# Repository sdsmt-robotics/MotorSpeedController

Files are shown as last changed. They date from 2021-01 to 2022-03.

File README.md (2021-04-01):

# MotorSpeedController  
yaya.

# Hardware  

# Software  
Contains code for the controller itself and code for a master device to interface with the controller.  
 * **controller** - Code for the speed controller itself.  
 * **controllerInterfaceLib** - Library files for use on a master device to interface with the controller.  
 
  ## Wiring Connections and Interface  
 This controller uses standard SPI communications.  
| Arduino | Speed Controller |
|---|---|
| 5V | 5V |
| GND | GND |
| MOSI | MOSI |
| MISO | MISO |
| SCK | SCK |
| SS* | SS |  

*The SS pin must be used for *at least one* of the connections. Additional speed controllers may use other digital IO pins.  
  
## Status LED  
The green LED on the board will indicate state of the controller. The key is as follows.
| State | Pattern |
|---|---|
| Off | ---------  |
| Brake | -\_\_-\_\_-\_\_  |
| Speed Control | --\_\_--\_\_-- |
| Power Control | --\_--\_--\_  |
| Timeout | -\_-\_-\_-\_-  |  
 
## Interface Lib Usage  
**Create:**  
Create an instance of the class.  

    Nidec24hController motor(SPI, ssPin);  

*SPI* - the SPI singleton object from the SPI.h library.  
*ssPin* - pin to use as chip select. Should simply be SS for first controller.  

**Initialize:**  
Create an instance of the class.  

    setup() {
        ...
        // Init SPI
        SPI.begin ();
        SPI.setClockDivider(SPI_CLOCK_DIV4);
        
        //Init motor controller
        motor.init();  
        ...
    }

**Set Speed:**  
Set the speed for the motor in RPM. Negative values are allowed. This will switch the motor to speed control mode if in power control mode or braking.  

    motor.setSpeed(speed);  

*speed* - the speed for the motor in RPM.  

**Set Power:**  
Set the power for the motor (-1000 to 1000). This will switch the motor to power control mode if in speed control mode or braking.  

    motor.setPower(power);  

*power* - the power for the motor (-1000 to 1000).  

**Brake:**  
Engage the electronic braking and stop the motor..  

    motor.brake();  

**Set Direction Inverted:**  
Set whether the motor control should be inverted.  

    motor.invertDirection(invertDir);  

*invertDir* - boolean to set if direction should be inverted.  

**Get Current Speed:**  
Get the current speed of the motor in RPM.   

    motor.getSpeed();  

**Get Current Power:**  
Get the current power the motor is running at. If in speed control mode, this will be varied automatically by the PID algorithm.  

    motor.getPower();  

**Get the Target Speed:**  
Get the target speed the controller is attempting to regulate the motor at.  

    motor.getTargetSpeed();

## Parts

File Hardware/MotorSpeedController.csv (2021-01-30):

Item | Qty | Reference(s) | Value | LibPart | Footprint | Datasheet | Digikey
1 | 2 | C1, C9 | 1uF | Device:C_Small | Capacitor_SMD:C_0603_1608Metric | ~ | 587-6280-1-ND
2 | 2 | C2, C4 | 22pF | Device:C_Small | Capacitor_SMD:C_0603_1608Metric | ~ | 478-0603YA220KAT2ACT-ND
3 | 5 | C3, C5, C6, C7, C8 | 0.1uF | Device:C_Small | Capacitor_SMD:C_0603_1608Metric | ~ | 1276-1941-1-ND
4 | 2 | D1, D2 | LED_Small_ALT | Device:LED_Small_ALT | Diode_SMD:D_0603_1608Metric_Castellated | ~ | 160-1183-1-ND
5 | 1 | D3 | D_Small | Device:D_Small | Diode_SMD:D_2010_5025Metric_Castellated | ~ | 478-7812-1-ND | DNP
6 | 3 | H1, H2, H3 | MountingHole_Pad | Mechanical:MountingHole_Pad | MountingHole:MountingHole_3mm_Pad_Via | ~ |  | DNP
7 | 1 | J1 | Conn_01x08_Female | Connector:Conn_01x08_Female | Connector_PinHeader_2.54mm:PinHeader_1x08_P2.54mm_Vertical | ~ |  | DNP
8 | 1 | J2 | Conn_01x05_Female | Connector:Conn_01x05_Female | Connector_PinHeader_2.54mm:PinHeader_1x05_P2.54mm_Vertical | ~ |  | DNP
9 | 1 | R1 | 1k | Device:R_Small | Resistor_SMD:R_0603_1608Metric | ~ | P124100CT-ND
10 | 2 | R2, R3 | 10k | Device:R_Small | Resistor_SMD:R_0603_1608Metric | ~ | P124100CT-ND
11 | 1 | U1 | ATmega328P-AU | MotorController:ATmega328P-AU | Package_QFP:TQFP-32_7x7mm_P0.8mm
12 | 1 | U2 | AS5134 | MotorController:AS5134 | MotorSpeedController:SOIC-20 |  | AS5134-ZSSMCT-ND
13 | 1 | U3 | MC7805 | MotorController:MC7805 | Package_TO_SOT_SMD:TO-252-2 |  | MC7805CDTRKGOSCT-ND
14 | 1 | Y1 | 16MHz | Device:Crystal_GND24_Small | Crystal:Crystal_SMD_3225-4Pin_3.2x2.5mm | ~ | 2151-RH100-16.000-12-1010-EXT-TRCT-ND

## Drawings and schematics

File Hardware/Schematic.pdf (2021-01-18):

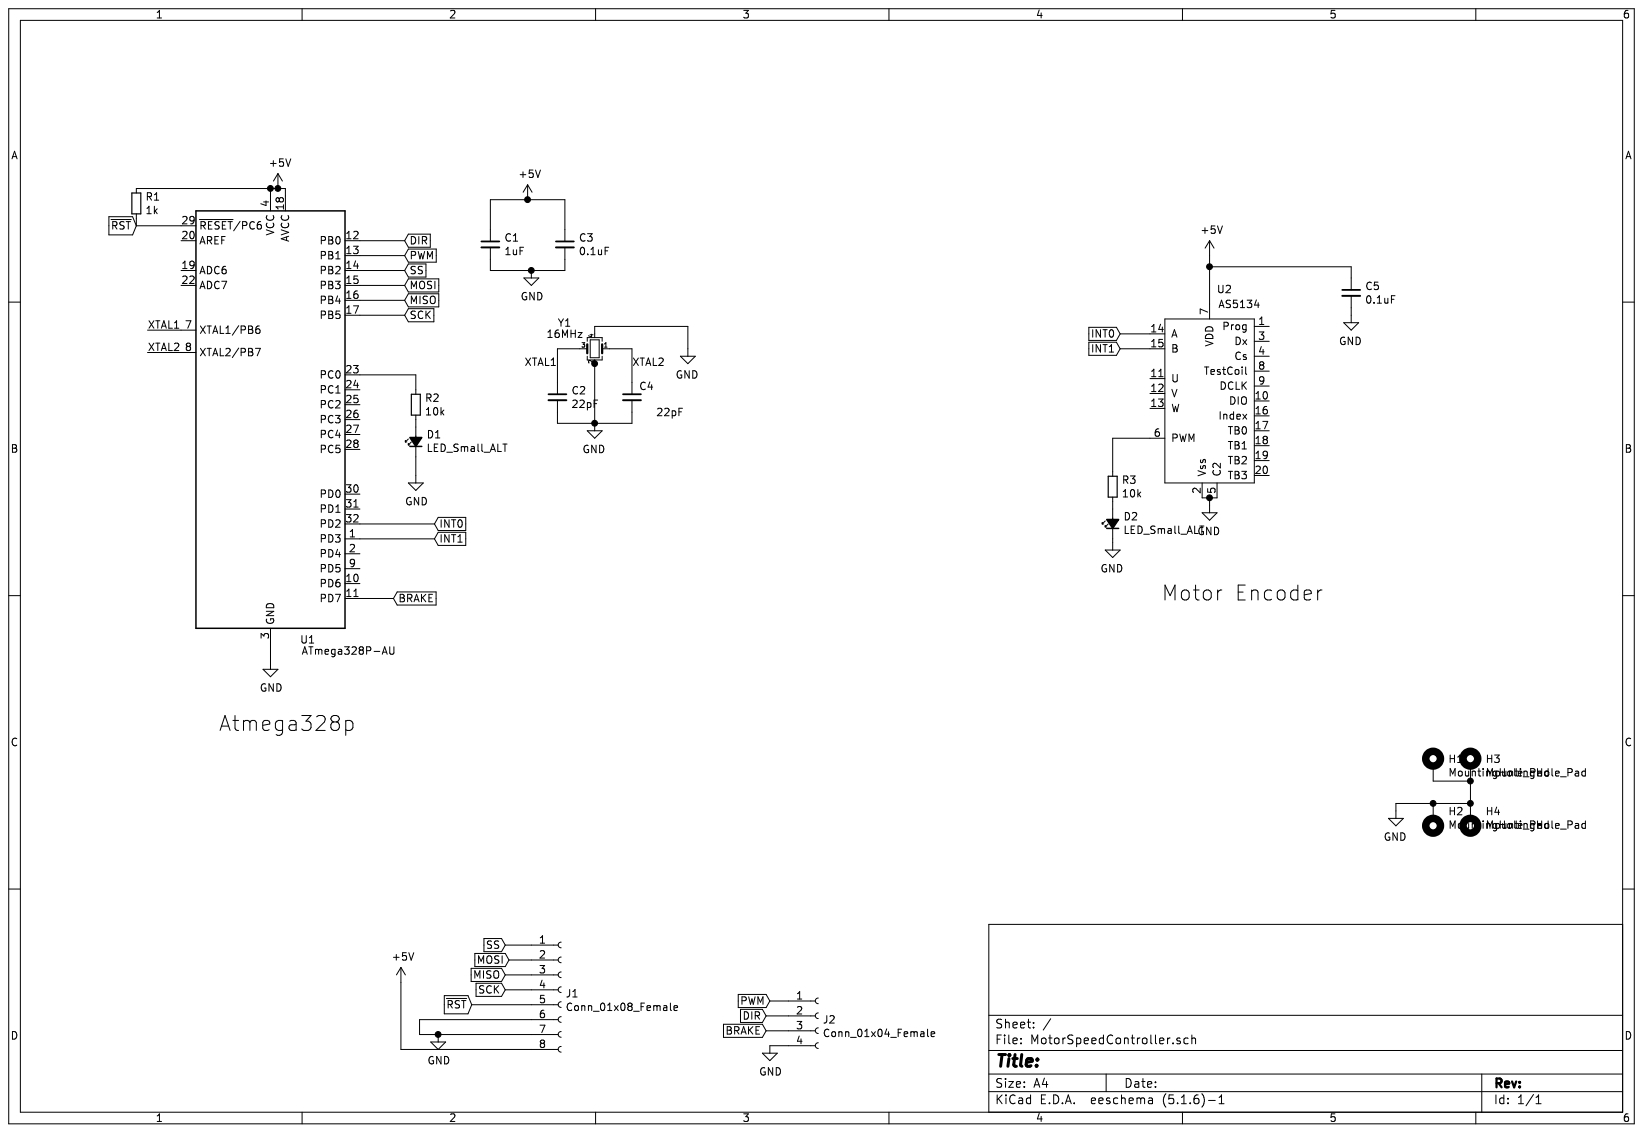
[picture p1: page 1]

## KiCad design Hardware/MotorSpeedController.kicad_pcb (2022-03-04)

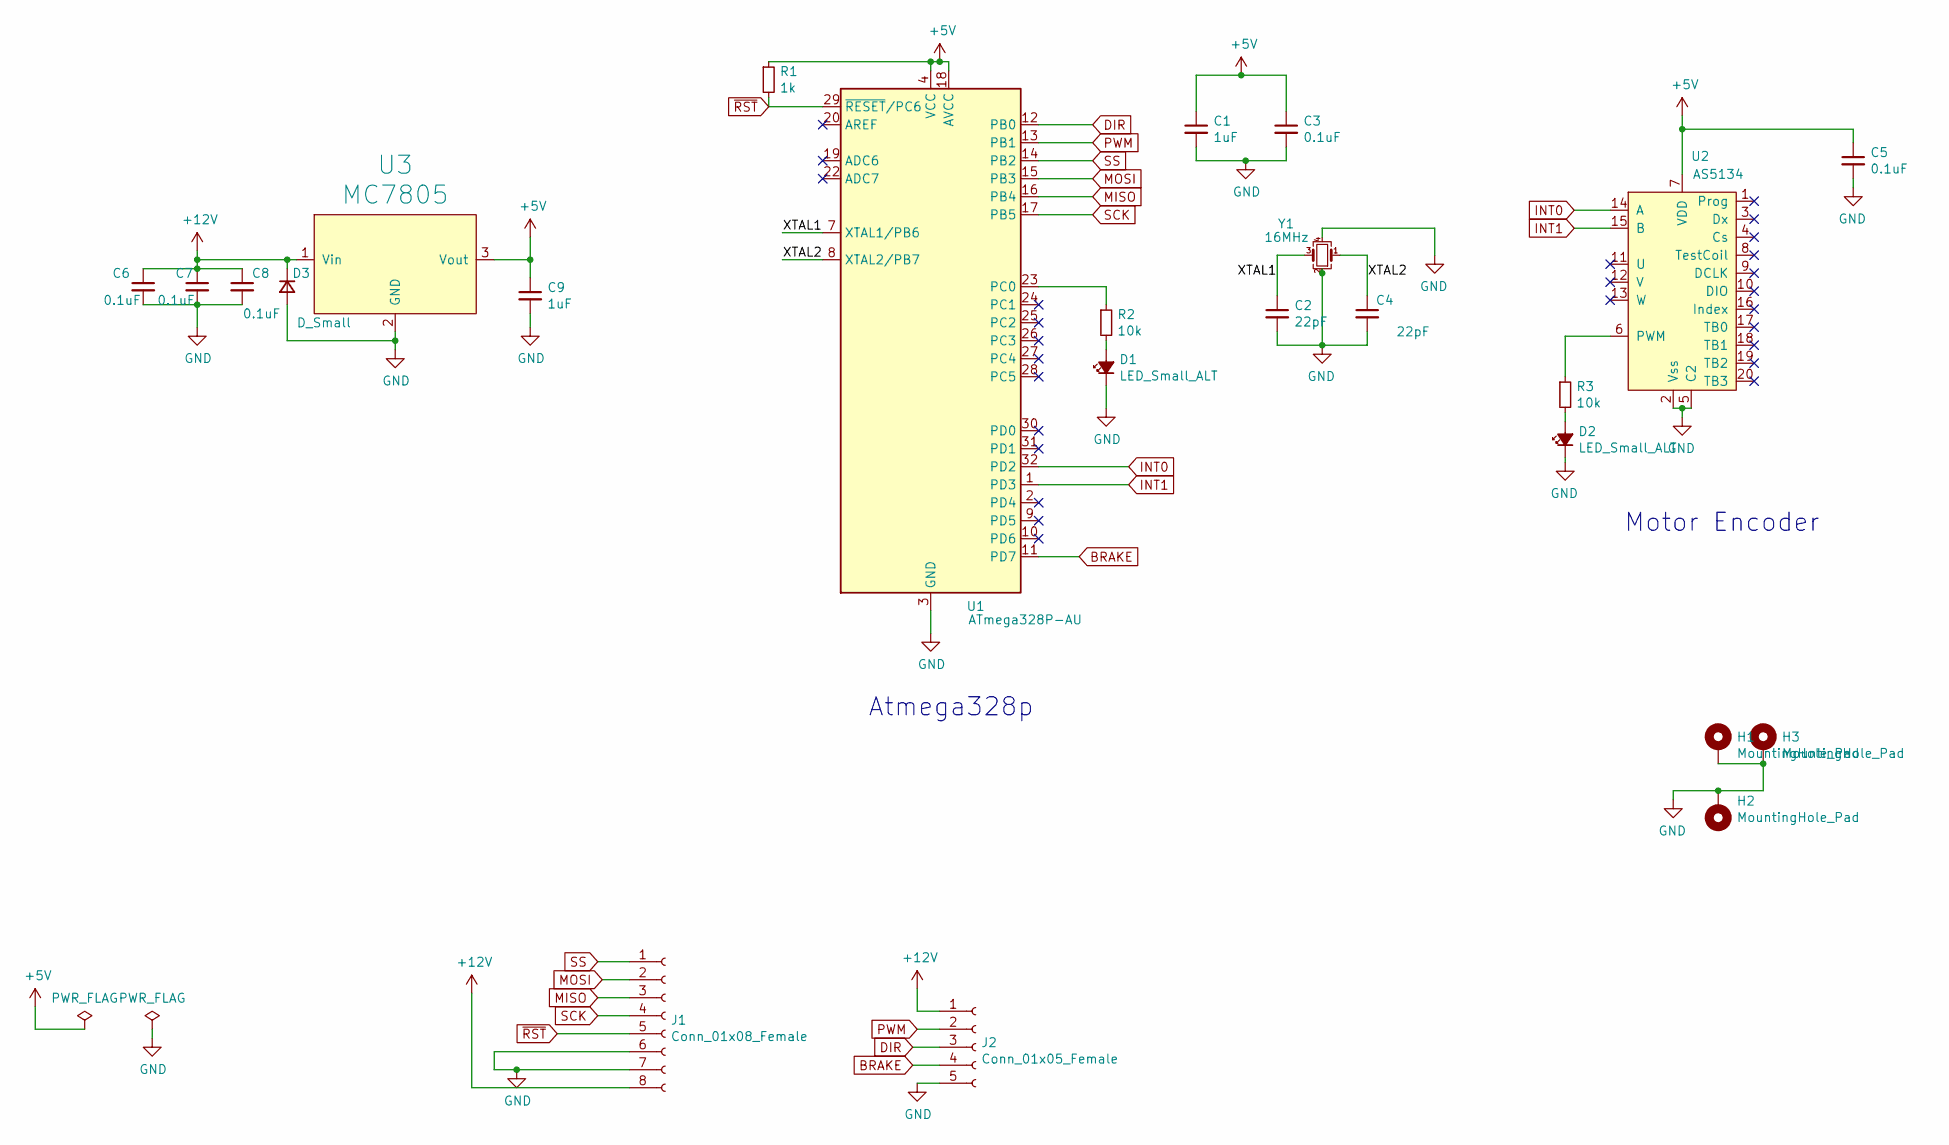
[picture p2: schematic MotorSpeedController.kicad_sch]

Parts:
C1, C9: 1uF; C_0603_1608Metric; Digikey 587-6280-1-ND‎
C2, C4: 22pF; C_0603_1608Metric; Digikey 478-0603YA220KAT2ACT-ND‎
C3, C5, C6, C7, C8: 0.1uF; C_0603_1608Metric; Digikey 1276-1941-1-ND
D1: LED_Small_ALT; D_0603_1608Metric_Castellated; Digikey 160-1183-1-ND
D2: LED_Small_ALT; D_0603_1608Metric_Castellated; Digikey 160-1182-1-ND‎
D3: D_Small; D_2010_5025Metric_Castellated; Digikey 478-7812-1-ND
H1, H2, H3: MountingHole_Pad; MountingHole_3mm_Pad_Via
J1: Conn_01x08_Female; PinHeader_1x08_P2.54mm_Vertical
J2: Conn_01x05_Female; PinHeader_1x05_P2.54mm_Vertical
R1: 1k; R_0603_1608Metric; Digikey P124100CT-ND‎
R2, R3: 10k; R_0603_1608Metric; Digikey P124100CT-ND‎
U1: ATmega328P-AU; TQFP-32_7x7mm_P0.8mm
U2: AS5134; SOIC-20; Digikey AS5134-ZSSMCT-ND‎
U3: MC7805; TO-252-2; Digikey MC7805CDTRKGOSCT-ND
Y1: 16MHz; Crystal_SMD_3225-4Pin_3.2x2.5mm; Digikey 2151-RH100-16.000-12-1010-EXT-TRCT-ND

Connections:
+5V: C1.1, C3.1, C5.1, C9.1, R1.1, U1.4 (VCC), U1.6 (VCC), U1.18 (AVCC), U2.7 (VDD), U3.3 (Vout)
+12V: C6.1, C7.1, C8.1, D3.1 (K), J1.8, J2.1, U3.1 (Vin)
/XTAL1: C2.1, U1.7 (XTAL1/PB6), Y1.3
/XTAL2: C4.1, U1.8 (XTAL2/PB7), Y1.1
BRAKE: J2.4, U1.11 (PD7)
DIR: J2.3, U1.12 (PB0)
GND: C1.2, C2.2, C3.2, C4.2, C5.2, C6.2, C7.2, C8.2, C9.2, D1.1 (K), D2.1 (K), D3.2 (A), H1.1, H2.1, H3.1, J1.6, J1.7, J2.5, U1.3 (GND), U1.5 (GND), U1.21 (GND), U2.2 (Vss), U2.5 (C2), U3.2 (GND), Y1.2, Y1.4
INT0: U1.32 (PD2), U2.14 (A)
INT1: U1.1 (PD3), U2.15 (B)
MISO: J1.3, U1.16 (PB4)
MOSI: J1.2, U1.15 (PB3)
unnamed: D1.2 (A), R2.2
unnamed: D2.2 (A), R3.2
unnamed: R2.1, U1.23 (PC0)
unnamed: R3.1, U2.6 (PWM)
PWM: J2.2, U1.13 (PB1)
SCK: J1.4, U1.17 (PB5)
SS: J1.1, U1.14 (PB2)
~RST: J1.5, R1.2, U1.29 (~RESET/PC6)

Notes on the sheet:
Motor Encoder
Atmega328p

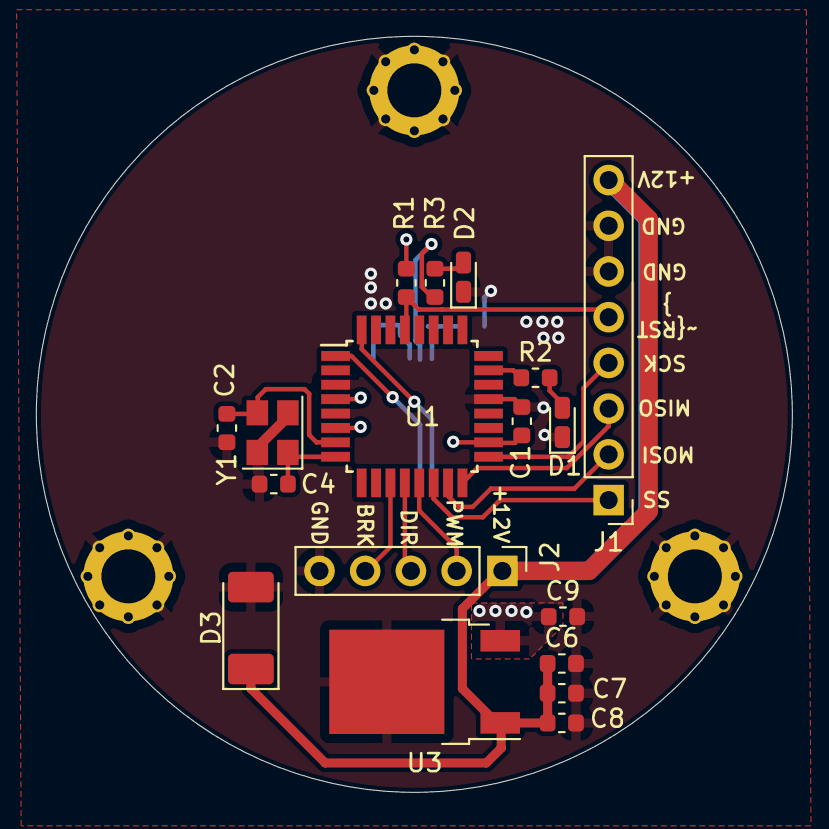
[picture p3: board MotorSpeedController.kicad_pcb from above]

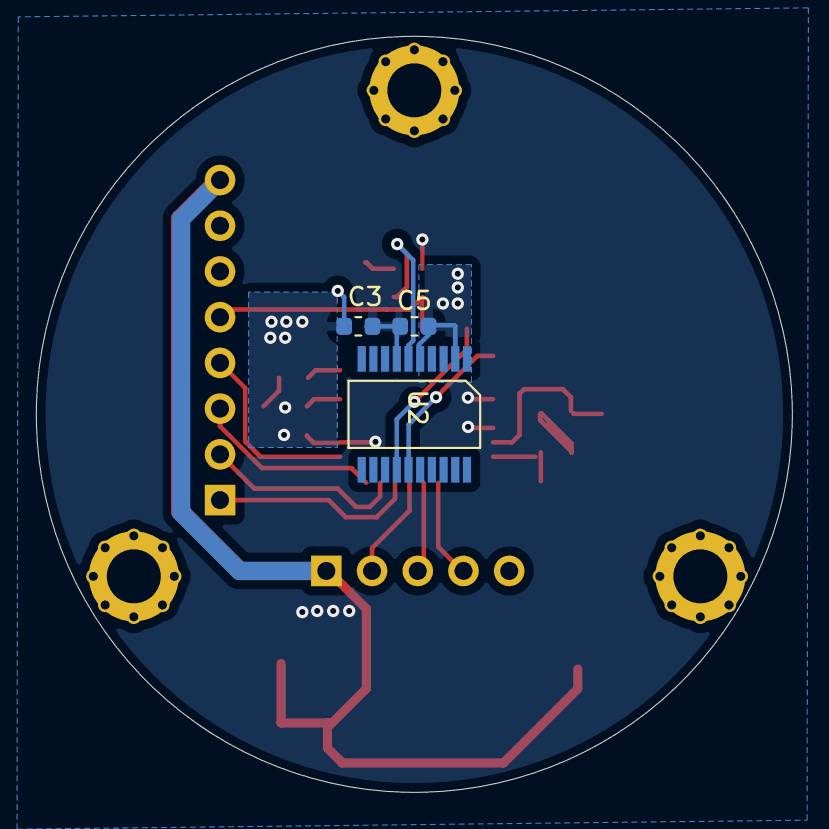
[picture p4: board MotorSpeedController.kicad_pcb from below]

Board: 2 copper layers, 42.0 x 42.0 mm, 24 parts (3 on the bottom side), 19 nets.

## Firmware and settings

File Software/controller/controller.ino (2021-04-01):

/*
 * Main program for the motor controller. Receive commands and values over SPI and 
 * manage motor as instructed. The hardware is as follows:
 *  - ATMEGA328P
 *  - SN74AHCT541N (level shifter)
 *  - Nidec24H brushless DC motor
 *  - AS5134 magnetic encoder (used in quadrature mode)
 * 
 * The motor controller can be in three states:
 *  - Speed control
 *  - Power control
 *  - Brakeing
 * The motor direction can also be inverted. The commands to perform these actions 
 * are sent over SPI along with the associated values. Requests for current values 
 * can also be sent over SPI.
 * 
 * Notes on the SPI:
 *  - works well at around 1MHz. Might work faster, but can be iffish.
 *  - Should leave at least 200us between commmunications.
 *  - (For some reason) input voltage to the ATMEGA328P for the SPI must be <5V. Higher 
 *    will cause failed transmissions.
 * 
 */


#include "Nidec24H.h"
#include "Encoder.h"
#include "PID.h"
#include <stdint.h>

// Define the pins
#define LED_PIN A0

#define MTR_PWM_PIN 9
#define MTR_BRAKE_PIN 7
#define MTR_DIR_PIN 8

#define ENC_A_PIN 2
#define ENC_B_PIN 3

// Define SPI Commands and commnumication stuff
// Commands
#define SET_SPEED        0x01
#define SET_POWER        0x02
#define SET_BRAKE        0x03
#define SET_INVERT_DIR   0x04
#define SET_TIMEOUT      0x05

#define GETTER_COMAND    0x10
#define GET_SPEED        0x00 | GETTER_COMAND
#define GET_POWER        0x01 | GETTER_COMAND
#define GET_TARGET_SPEED 0x02 | GETTER_COMAND

// SPI Send/receive variables
volatile byte spiCommand = 0;        // Command received from the controller
volatile byte spiByteNum = 0;        // Current send/receive status
volatile int16_t spiVal = 0;         // Value being sent or received
volatile bool dataReceived = false;  // Track if we have new data
const byte SPI_COM_END = 2;          // Number of the final send/receive byte
const long SPI_TIMEOUT = 100;        // Max time a byte should take (in microseconds)

const int MAX_RPM = 6000;  // Maximum RPM we could ask the motor to run

// Struct for receiving data
union SpiData
{
  int16_t val;
  struct
  {
    uint8_t lsb;
    uint8_t msb;
  };
};

// Time last update received from the controller
// TODO: add a timeout?
unsigned long lastReceive = 0;
unsigned long timeout = 0;
volatile bool receivedCommand = false;

// Controller update interval in microseconds
const unsigned long UPDATE_INTERVAL = 2000;

// Define blink patterns
union BlinkPattern
{
  unsigned long time[2];
  struct
  {
    unsigned long offTime;
    unsigned long onTime;
  };
};
const BlinkPattern BRAKE_BLINK = {1000, 200};
const BlinkPattern SPEED_BLINK = {500, 500};
const BlinkPattern POWER_BLINK = {200, 1000};
const BlinkPattern TIMEOUT_BLINK = {200, 200};

// Motor control states
enum MotorState {SPEED_CONTROL, POWER_CONTROL, BRAKE, TIMEOUT};
volatile MotorState motorState = TIMEOUT;

//Create the motor control object
//Nidec24H(dirPin, brakePin)
Nidec24H motor(MTR_DIR_PIN, MTR_BRAKE_PIN);

// Create the encoder reader object
// Encoder(int aPin, int bPin, int ticksPerRotation)
Encoder encoder(ENC_A_PIN, ENC_B_PIN, 360);

//motor speed controller
// TODO: add support for reading and saving these values from EEPROM
//float kp = 5, ki = 7, kd = 0.5 , kf = 1/10.0, N = 10;
float kp = 5, ki = 12, kd = 0.2 , kf = 1/10.0, N = 10;
//float kp = 1.0, ki = 0.0, kd = 0.0 , kf = 0.16, N = 1;
// PID(Kp, Ki, Kd, N, sample_time)
PID pid(kp, ki, kd, kf, N, UPDATE_INTERVAL);
double setpoint = 1;


//=====SETUP=========================================================
void setup() {
  // Initialize the SPI for the device
  initSpi();

  //initialize the speed control
  pid.setLimits(-1000, 1000);
  pid.setTarget(setpoint);

  // initialize the motor
  motor.init();

  // Initialize the encoder 
  encoder.init();

  // Init LED control
  pinMode(LED_PIN, OUTPUT);
  digitalWrite(LED_PIN, LOW);

  lastReceive = millis();
}


//=====LOOP=========================================================
void loop() {
  static unsigned long lastUpdate = micros();  // Last time the current speed and motor control PID got updated

  while (true) {
    // Timeout if haven't received a transmission in a while
    if (receivedCommand) {
      lastReceive = millis();
      receivedCommand = false;
    } else if ((motorState != TIMEOUT) && (timeout != 0) && (millis() - lastReceive > timeout)) {
      motorState = TIMEOUT;
      motor.setPower(0);
    }

    // Control the motor
    if (motorState != TIMEOUT) {
      // Control the motor
      if (micros() - lastUpdate > UPDATE_INTERVAL) {
        encoder.estimateSpeed();
        
        if (motorState == SPEED_CONTROL) {
          //Get the power level from the speed controller
          int power = pid.calculateOutput(encoder.getFilteredSpeed());
      
          //set the motor power
          motor.setPower(power);
        }
        
        lastUpdate = micros();
      }
    }

    // Update the LED blink
    updateLed();
  }
}

/**
 * @brief Control the LED blink pattern.
 */
void updateLed() {
  static bool state = LOW;
  static unsigned long lastTransition = millis();
  bool newState = state;

  // Figure out what pattern should blink
  if (motorState == SPEED_CONTROL) {
    if (millis() - lastTransition > SPEED_BLINK.time[state]) {
      newState = !state;
    }
  } else if (motorState == POWER_CONTROL) {
    if (motor.getPower() == 0) {
      newState = HIGH;
    } else if (millis() - lastTransition > POWER_BLINK.time[state]) {
      newState = !state;
    }
  } else if (motorState == BRAKE) {
    if (millis() - lastTransition > BRAKE_BLINK.time[state]) {
      newState = !state;
    }
  } else if (motorState == TIMEOUT) {
    if (millis() - lastTransition > TIMEOUT_BLINK.time[state]) {
      newState = !state;
    }
  }

  // Update the LED state if needed
  if (state != newState) {
    digitalWrite(LED_PIN, newState);
    state = newState;
    lastTransition = millis();
  }
}

//=====SPI functions==========================
/**
 * @brief Initialize the SPI communications for the slave device.
 */
void initSpi() {
  // have to send on master in, *slave out*
  pinMode(MISO, OUTPUT);

  // turn on SPI in slave mode
  SPCR |= _BV(SPE);

  // turn on interrupts
  SPCR |= _BV(SPIE);
  

  // turn on SPI in slave mode
  SPCR |= _BV(SPE);

  // turn on interrupts
  SPCR |= _BV(SPIE);

  // Initialize SPI timeout timer
  TIMSK2 = 0; // Diable interrupts
  TCCR2A = 0;
  TCCR2B = 0;  // 
  TCNT2  = 0;  // Clear counter

  TCCR2A |= (1 << WGM21);                // CTC mode
  TCCR2B |= (1 << CS21) | (1 << CS20);   // 128 prescaler 
}

/**
 * @brief Construct the ISR for the SPI communications. Called when SPDR gets a new byte.
 */
ISR (SPI_STC_vect) {
  // Read the fist byte (the command)
  noInterrupts();

  spiCommand = SPDR;
  // Get the value if doing a send (Switch takes ~12us worst case, ~3.5us avg)
  if (spiCommand & GETTER_COMAND) {
    switch (spiCommand) {
      case GET_SPEED:  // Current speed of the motor
        spiVal = encoder.getFilteredSpeed();
        break;

      case GET_POWER:  // Current power set for the motor
        spiVal = motor.getPower();
        break;

      case GET_TARGET_SPEED:  // Target speed of the motor
        spiVal = pid.getTarget();
        break;
      
      default: // Just send 0. Garbage request
        spiVal = 0x0;
        break;
    }
  } else {
    spiVal = 0x0;
  }

  // Do the data transfer
  bool success = transferData(spiVal);

  // Handle data we received
  if (success) 
    handleReceivedData(spiCommand, spiVal);

  interrupts();
  
  // Let the loop know we got a communicaiton
  receivedCommand = true;
}


/**
* @brief do stuff with the data that was received over SPI.
* 
* @param command - the command that came with the data
* @param value - received data
*/
void handleReceivedData(byte command, int value) {
    // Do the thing with the value if receiving
    if (!(command & GETTER_COMAND)) {
      // Do what we need to with it
      switch (command) {
        case SET_SPEED:  // Set current speed of the motor
          if (motorState != SPEED_CONTROL) { // Do a reset if changing modes so don't jump.
            pid.reset();
          }

          // Consrain to make sure not trying to set to high
          if (value > MAX_RPM)
            value = MAX_RPM;
          else if (value < -MAX_RPM)
            value = -MAX_RPM;
          
          pid.setTarget(value);
          motorState = SPEED_CONTROL;
          break;

        case SET_POWER:  // Set current speed for motor and go into power control mode
          motorState = POWER_CONTROL;
          motor.setPower(value);
          break;

        case SET_BRAKE:  // Stop the motor
          motorState = BRAKE;
          motor.brake();
          break;
        
        case SET_INVERT_DIR:  // Set whether default motor direction should be inverted
          motor.invertDirection(value);
          encoder.invertDirection(value);
          if (motorState == SPEED_CONTROL) { // Do a reset if in speed control mode so don't jump.
            pid.reset();
          }
          break;
        case SET_TIMEOUT:
          timeout = value;
          break;
      }
      
    }
}

/**
 * @brief transfer the data through SPI
 * 
 * @param data - the value to send and variable to take received value
 * @return true if transmission success, false otherwise (timeout).
 */
bool transferData(volatile int16_t &data) {
    static SpiData in, out;

    in.val = data;

    // Send/Receive the LSB
    SPDR = in.lsb;
    asm volatile("nop");
    resetMicroTimer();
    while (!spiByteReceived()) {
      if (microTimer() > (SPI_TIMEOUT << 1)) {
        return false;
      }
    }
    out.lsb = SPDR;
    
    // Send/Receive the MSB
    SPDR = in.msb;
    asm volatile("nop");
    resetMicroTimer();
    while (!spiByteReceived()) {
      if (microTimer() > SPI_TIMEOUT) {
        return false;
      }
    }
    out.msb = SPDR;
    data = out.val;
    return true;
}

/**
 * Get the current time in us since reset.
 */
unsigned microTimer() {
  // 16 MHz cpu, 32 prescaler
  return TCNT2 * 2;
}

/**
 * Reset the timer.
 */
void resetMicroTimer() {
  TCNT2 = 0;
}


/**
* @brief check if a SPI transmission has been received
* 
* @return true if received a byte over SPI
*/
inline bool spiByteReceived() {
  return SPSR & _BV(SPIF);
}

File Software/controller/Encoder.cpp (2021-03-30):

/* 
 * Class for the Encoder.
 * This class provides functions for tracking encoder ticks and determining speed.
 * 
 * Note: this class is only set up to support one encoder. Attempting to use it for more will break things.
 */

#include "Encoder.h"

// for use by ISR routine
Encoder * Encoder::instance;
/**
 * @brief Constructor for the class.
 * 
 * @param aPin - First encoder pin. Attached to interrupt.
 * @param bPin - second encoder pin.
 * @param ticksPerRotation - Number of encoder ticks per rotation.
 */
Encoder::Encoder(int aPin, int bPin, int ticksPerRotation) 
    : aPin(aPin), bPin(bPin), ticksPerRotation(ticksPerRotation), speedFilter(100, 100, 0.08)  { //speedFilter(300, 300, 0.025)
}

/**
 * @brief Initialize the encoder.
 */
void Encoder::init() {
    //Setup control pins
    pinMode(aPin, INPUT_PULLUP);
    pinMode(bPin, INPUT_PULLUP);
    
    //Set up the encoder interrupt pin
    int intNumA = digitalPinToInterrupt(aPin);
    int intNumB = digitalPinToInterrupt(bPin);
    instance = this;
    attachInterrupt(intNumA, Encoder::isrA, CHANGE);
    attachInterrupt(intNumB, Encoder::isrB, CHANGE);

    // Get the register and bit for the pins to make the ISR a bit faster
    aPinRegister = portInputRegister(digitalPinToPort(aPin));
    aPinBit = digitalPinToBitMask(aPin);
    bPinRegister = portInputRegister(digitalPinToPort(bPin));
    bPinBit = digitalPinToBitMask(bPin);
    
    //initialize the timer
    lastTickTime = micros();
    lastEstTime = lastTickTime;
}


/**
 * @brief set whether the encodeer's readings should be inverted.
 * 
 * @param invertDir - true if should be inverted, false otherwise
 */
void Encoder::invertDirection(bool invertDir) {
  this->invertDir = invertDir;
}

/**
 * Update the current speed estimate and return the filtered value.
 */
int Encoder::estimateSpeed() {
  // Calculate the speed if we got a tick. Otherwise assume 0.
  if (lastTickTime != lastEstTime) {
    speed = ticks * (tickConversion / (lastTickTime - lastEstTime));
  } else {
    speed = 0;
  }
  
  // Reset things
  lastEstTime = lastTickTime;
  ticks = 0;

  // Invert if needed
  if (invertDir) {
    speed = -speed;
  }

  // Filter
  filteredSpeed = speedFilter.updateEstimate(speed);


  // Return the speed
  return filteredSpeed;
}

/**
 * @brief Get the current speed the motor is running at in RPMs.
 * 
 * @return the current speed of the motor.
 */
int Encoder::getSpeed() {
  return speed;
}

/**
 * @brief Get the filtered current speed the motor is running at in RPMs.
 * 
 * @return the filtered current speed of the motor.
 */
int Encoder::getFilteredSpeed() {
  return filteredSpeed;
}

/**
 * Count a tick and set the last tick time.
 * 
 * NOTE: This ISR takes about 8 microseconds.
 * 
 * @param trigA - interrupt triggered by channel A or no.
 */
void Encoder::tick(bool trigA) {
  lastTickTime = micros();

  // Get current pin values
  bool aLevel = (*aPinRegister) & aPinBit;
  bool bLevel = (*bPinRegister) & bPinBit;

  // Increase or decrease depending on combination and which pin triggered the interrupt
  if (trigA != (aLevel == bLevel)) {
    ++ticks;
  } else {
    --ticks;
  }
}


/**
 * @brief Handle interrupt. Forward it to stored instance.
 */
void Encoder::isrA() {
  instance->tick(true);
}

void Encoder::isrB() {
  instance->tick(false);
}

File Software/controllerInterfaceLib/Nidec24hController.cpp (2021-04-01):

/**
 * Class for interfacing with the Nidec24h motor controller.
 * 
 * init() - intialize the class.
 * 
 * setSpeed(speed) - Set the speed for the motor in rpm.
 * setPower(power) - Set the power for the motor in the range -1000 to 1000.
 * brake() - invertDirection(invertDir) - set whether motor control should be inverted (t/f).
 * 
 * getSpeed() - Get the current speed of the motor in rpm.
 * getPower() - Get the current set power of the motor in the range -1000 to 1000.
 * getTargetSpeed() - Get the set target speed of the controller.
 */

#include "Nidec24hController.h"

// Commands
#define SET_SPEED        0x01
#define SET_POWER        0x02
#define SET_BRAKE        0x03
#define SET_INVERT_DIR   0x04
#define SET_TIMEOUT      0x05

#define GETTER_COMAND    0x10
#define GET_SPEED        0x00 | GETTER_COMAND
#define GET_POWER        0x01 | GETTER_COMAND
#define GET_TARGET_SPEED 0x02 | GETTER_COMAND


/**
 * @brief Constructor for the class.
 */
Nidec24hController::Nidec24hController(SPIClass &spi, int ssPin) : spi(spi), ssPin(ssPin) {
  
}

/**
 * Initialize the class.
 */
void Nidec24hController::init() {
  pinMode(ssPin, OUTPUT);  // Shouldn't have to do this, but some devices need it
  digitalWrite(SS, HIGH);  // ensure SS stays high for now
  digitalWrite(ssPin, HIGH);

  // Initialize motor control
  invertDirection(0);
  setPower(0);
  
  lastCommunication = micros();
}


/**
 * @brief Set the target speed of the motor in RPM.
 * 
 * @param speed - new speed for the motor.
 */
void Nidec24hController::setSpeed(int speed) {
  sendVal(SET_SPEED, speed);
}

/**
 * @brief Set the power for the motor. Value in the range -1000 to 1000.
 * 
 * @param power - new power level for the motor
 */
void Nidec24hController::setPower(int power) {
  sendVal(SET_POWER, power);
}

/**
 * @brief Set the timeout for the motor. Setting to 0 will disable timeout.
 * 
 * @param timeout - new timeout for the motor (in ms)
 */
void Nidec24hController::setTimeout(unsigned timeout) {
  sendVal(SET_TIMEOUT, timeout);
}

/**
 * @brief Stop the motor and engage braking.
 */
void Nidec24hController::brake() {
  sendVal(SET_BRAKE, 0);
}

/**
 * @brief Set whether motor direction should be inverted.
 * 
 * @param invertDir - set whether direction should be inverted
 */
void Nidec24hController::invertDirection(bool invertDir) {
  sendVal(SET_INVERT_DIR, invertDir);
}

/**
 * @brief Get the current speed the motor is running at in rpm.
 * 
 * @return the speed of the motor
 */
int Nidec24hController::getSpeed() {
  return getVal(GET_SPEED);
}

/**
 * @brief Get the current power set for the motor. In the range -1000 to 1000.
 * 
 * @return the power level of the motor.
 */
int Nidec24hController::getPower() {
  return getVal(GET_POWER);
}

/**
 * @brief Get the target speed (in rpm) the motor is trying to run at.
 * 
 * @return the target speed.
 */
int Nidec24hController::getTargetSpeed() {
  return getVal(GET_TARGET_SPEED);
}

/**
 * @brief Send a value to the device for the given command.
 * 
 * @param command - action to perform.
 * @param value - corresponding value for the action.
 */
void Nidec24hController::sendVal(uint8_t command, int value) {
  communicate(command, value);
}

/**
 * @brief Get a value from the device for the given command.
 * 
 * @param command - tell device which value to get.
 * @return the value returned from the device.
 */
int Nidec24hController::getVal(uint8_t command) {
  return communicate(command, 0);
}

/**
 * Communicate with the device. Send a command and then send a 16-bit value for the 
 * command and simultaneously read a response if present.
 * 
 * @param command - action to perform or value to get.
 * @param sendVal - corresponding value for the action.
 * @return the value returned from the device.
 */
int Nidec24hController::communicate(uint8_t command, int sendVal) {
  union { int16_t val; struct { uint8_t lsb; uint8_t msb; }; } in, out;
  
  out.val = sendVal;
  
  // Wait until minimum time has elapsed (otherwise speed controller can't keep up)
  while (micros() - lastCommunication < MIN_SEND_INTERVAL) { }

  noInterrupts();
  // Select the chip to control
  digitalWrite(ssPin, LOW);
  delayMicroseconds (TRANSFER_BYTE_DELAY/2);
  
  // Send the initial command
  spi.transfer(command); // Takes ~20us with 32 clock div
  delayMicroseconds(TRANSFER_BYTE_DELAY);

  // Send the value and (or) read the response
  in.lsb = spi.transfer(out.lsb);
  delayMicroseconds(TRANSFER_BYTE_DELAY/2);
  in.msb = spi.transfer(out.msb);
  
  // Done controlling
  delayMicroseconds(TRANSFER_BYTE_DELAY/2);
  digitalWrite(ssPin, HIGH);
  delayMicroseconds(TRANSFER_BYTE_DELAY/2);
  interrupts();
  
  lastCommunication = micros();

  // Turn the two values into a 16-bit value
  return in.val;
}

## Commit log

2021-01-17 Deleted Dupilicate file
    [MotorSpeedController.kicad_pcb]
2021-01-18 Working controller and interface code
    - Code for the controller is working as far as I can tell and so is the interface code.
    - PID values need adjusting.
    - Code could use some more testing.
    - Significant cleanup needed (sorry).
2021-01-18 Added pull downs in Interrupt pins
    [MotorSpeedController.kicad_pcb]
2021-01-19 Addded gitignore
    [MotorSpeedController.kicad_pcb]
2021-01-19 Added a discrete PID library
2021-01-20 Implement the new PID library
2021-01-23 Updated Footprints for better fit
    [MotorSpeedController.kicad_pcb, MotorSpeedController.sch]
2021-01-24 Changed PCB Dimensions. Added +5V regulator. Made headers bigger
    [MotorSpeedController.kicad_pcb, MotorSpeedController.sch]
2021-01-24 Prevent soldermask from Bottom +12V rail so we can solder wire to it
    [MotorSpeedController.kicad_pcb]
2021-01-27 Improved filter. Tuned PID
2021-01-30 Added Final CAM files and updated BOM
    [MotorSpeedController-B_Cu.gbr, MotorSpeedController-B_Mask.gbr, MotorSpeedController-B_Paste.gbr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]
2021-03-19 Improve SPI communication reliability on interface lib
2021-03-23 Further improve SPI reliability
2021-03-30 Add timer to prevent sending commands too quickly
    [Nidec24hController.cpp, communicationTest.ino]
2021-03-30 Adjust PID tuning and add blinking lights
2021-04-01 Improve SPI and add communication timeout
2022-03-04 Updated to KiCAD 6
    [MotorSpeedController-B_Cu.gbr, MotorSpeedController-B_Mask.gbr, MotorSpeedController-B_Paste.gbr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]
2022-03-04 Forgot to update zip file to KiCAD 6
